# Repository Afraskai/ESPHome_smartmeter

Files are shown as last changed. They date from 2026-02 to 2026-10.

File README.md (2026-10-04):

# esphome-sml-reader

**Language:** English | [Deutsch](README.de.md)

Read your electricity meter via its infrared (IR) interface — no wiring into mains required.  
Uses an **ESP32-C3 with OLED display** (ABRobot 0.42") and a **BPW40 photodiode** to receive SML data from an ISKRA smart meter. Values are pushed to **Home Assistant** over WiFi.

> **Requirement:** Unlock the meter's IR diode first. Enter the PIN on the meter front (per your utility instructions) so the IR LED turns on and detailed SML data becomes available.

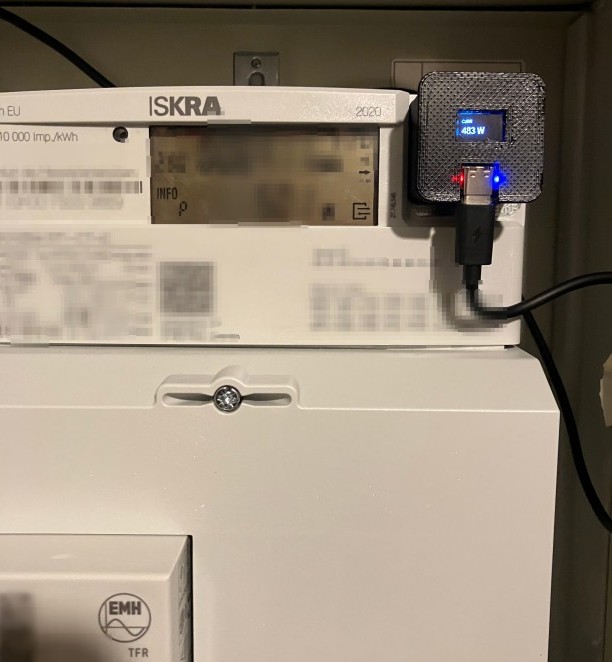
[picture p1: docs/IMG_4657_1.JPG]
Installed on meter


## Features

- **Real-time power** (W) — import and export
- **Total energy counters** (kWh) — grid import & grid export
- **Tiny OLED display** — cycles through current power, import total, export total
- **Blue LED** — blinks when data is being received
- **WiFi quality** — plain-language rating in 5 levels including dBm (e.g. `weak (-78 dBm)`)
- **Web dashboard** — built-in on port 80
- **OTA updates** — flash new firmware over WiFi

## ESPHome Web UI

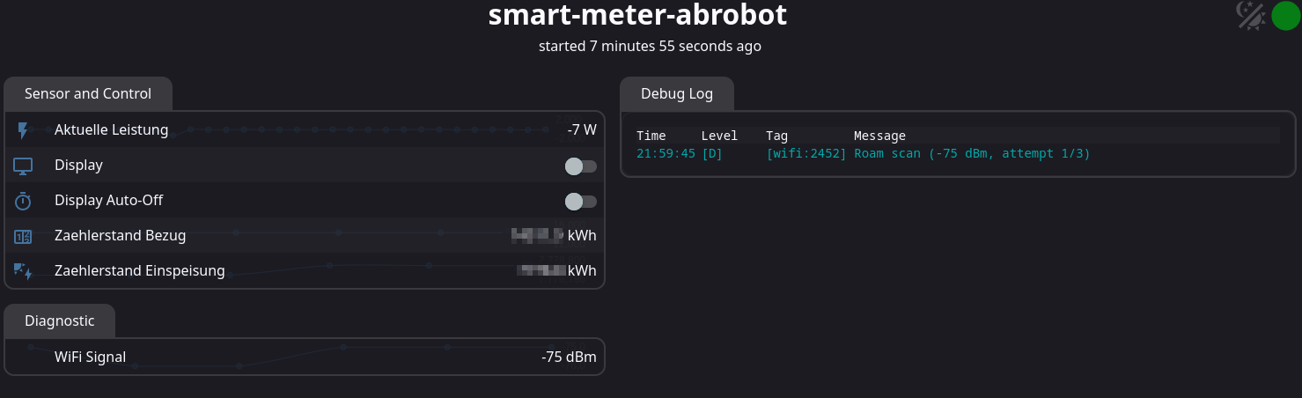
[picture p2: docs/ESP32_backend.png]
ESPHome device page


## What You Need

| Part | Notes |
|---|---|
| ESP32-C3 OLED board (ABRobot 0.42") | Has a built-in 72×40 SSD1306 display |
| BPW40 photodiode | Receives the IR signal from the meter |
| 1 kΩ resistor | Pull-down for the photodiode signal |
| 3D-printed case + magnet holder | Optional, but recommended for a clean install |
| Neodymium magnet (5 mm ⌀ × 3 mm) | Holds the case on the meter |
| USB-C cable + power supply | Powers the ESP32 inside the meter cabinet |

## Parts Overview

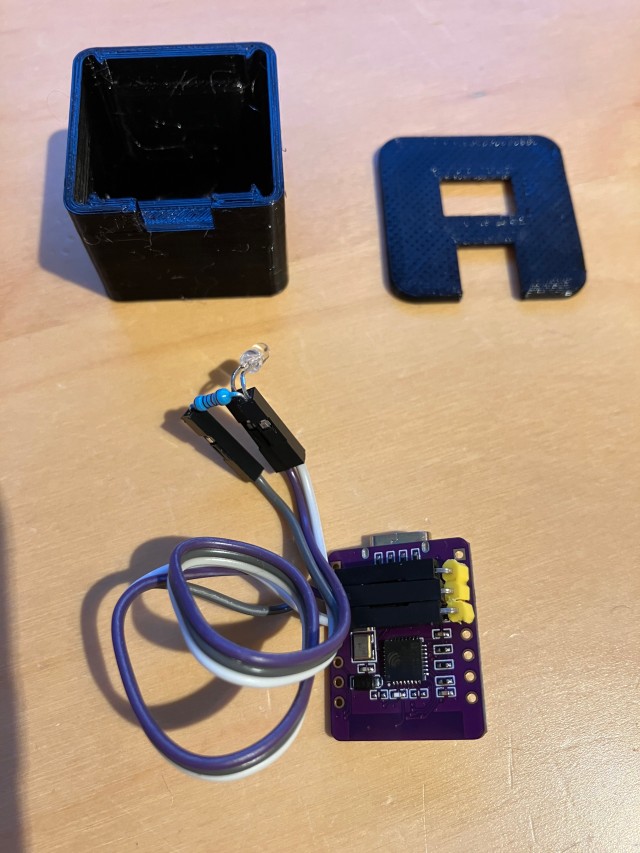
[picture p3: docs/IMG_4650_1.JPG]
Components


*Left to right: 3D-printed magnet holder, case with light-tight compartment for the photodiode, BPW40 + resistor on Dupont wires, ESP32-C3 ABRobot board.*

## Assembled Unit

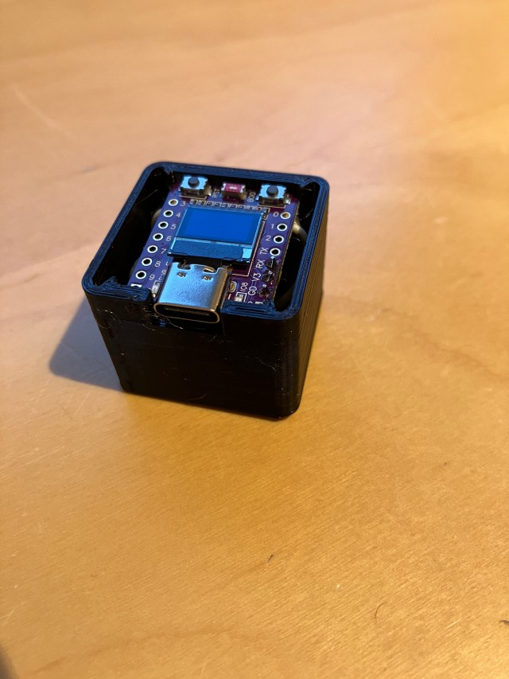
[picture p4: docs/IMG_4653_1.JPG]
ESP32 in case


*The ESP32-C3 sits in the 3D-printed case. The OLED display and USB-C port are accessible from the front.*

## Wiring Diagram

The BPW40 photodiode is connected to the ESP32-C3 with just three wires and one resistor:

```mermaid
graph LR
    subgraph "BPW40 Photodiode"
        K["Cathode (short leg)"]
        A["Anode (long leg)"]
    end

    subgraph "ESP32-C3 (ABRobot)"
        V3["3.3V"]
        RX["GPIO20 / RX"]
        GND["GND"]
    end

    R["1 kΩ Resistor"]

    K -- "purple wire" --> V3
    A -- "white wire" --> RX
    RX --> R
    R --> GND
```

> **Key point:** The photodiode is reverse-biased (cathode → 3.3V). The 1 kΩ resistor pulls GPIO20 to GND. When the meter's IR LED pulses, the photodiode conducts and the voltage on GPIO20 changes — the ESP32 UART reads this as serial SML data.

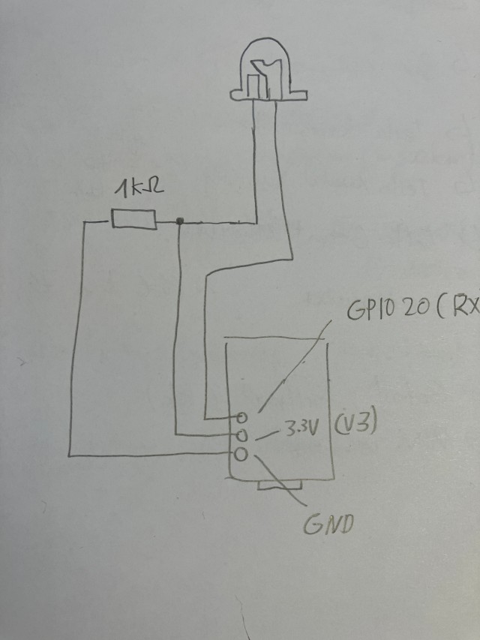
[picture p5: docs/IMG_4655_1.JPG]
Hand-drawn schematic


## Installation

1. **Flash the firmware**  
   Copy `esphome_smartmeter_en.yaml` (or `_de.yaml` for German) into your ESPHome dashboard and add your WiFi credentials to `secrets.yaml`:
   ```yaml
   wifi_ssid: "YourNetwork"
   wifi_password: "YourPassword"
   ```

   Tested with **ESPHome 2026.9.1** (dashboard or CLI).

2. **Wire the photodiode**  
   Connect the BPW40 as shown in the wiring diagram above.

3. **Prepare the 3D-printed case**  
   Depending on your printer and filament, the holes for the photodiode legs may be too tight. You might need to drill them out — a **3 mm drill bit** worked well in my case.

4. **Mount on the meter**  
   Press the neodymium magnet (5 mm ⌀ × 3 mm) into the holder. Place the photodiode directly over the meter's IR interface. It **must** be light-tight — use the 3D-printed case or black tape. The magnet snaps the unit onto the meter housing.

5. **Power up**  
   Plug in the USB-C cable. The display will show "Waiting…" until the first SML telegram arrives (usually within a few seconds).

6. **Add to Home Assistant**  
   The device will be auto-discovered via the ESPHome integration. You get three sensors:
   - **Current Power** (W)
   - **Grid Import Total** (kWh)
   - **Grid Export Total** (kWh)
   - **WiFi Quality** (text, e.g. `good (-58 dBm)`)

> **Tip:** Smart meter cabinets are often metal and shield WiFi. Make sure the ESP32 gets a reliable signal — the `WiFi Quality` sensor shows you how good it actually is.

## Installed on the Meter

Installed

*The reader sits next to the ISKRA meter in the cabinet. The OLED shows the current power draw (483 W in this photo). The blue LED confirms active data reception.*

## Display Pages

The OLED cycles automatically every 5 seconds:

| Page | Label | Value |
|---|---|---|
| 1 | `CURR` | Current power in W |
| 2 | `IMPORT` | Total grid import in kWh |
| 3 | `EXPORT` | Total grid export in kWh |

## WiFi Quality

The `WiFi Quality` text sensor rates the signal in five levels and appends the raw value in brackets — e.g. `weak (-78 dBm)`. It shows up in the web dashboard and in Home Assistant. The underlying numeric RSSI sensor is marked `internal`, so it does not appear as a separate entity.

| Signal strength | Rating |
|---|---|
| ≥ -50 dBm | excellent |
| -50 to -59 dBm | good |
| -60 to -69 dBm | fair |
| -70 to -79 dBm | weak |
| < -80 dBm | very weak |

> **Note:** Right after a restart the sensor reads `unknown` for about a minute — it polls every 60 seconds and on the first poll after boot the WiFi sensor has no value yet. The real reading follows.

## Compatibility

Tested with **ISKRA** smart meters using the **SML protocol** over IR. Should work with any SML-capable meter — you may need to adjust the OBIS codes in the YAML config for your specific meter model.

## Contributing

Contributions, issues, and feature requests are welcome! Feel free to open an issue or submit a pull request.

## License

This project is open source and available under the [MIT License](LICENSE).

## Disclaimer

This project is provided **as-is**, without any warranty of any kind, express or implied. Use it at your own risk. The author assumes **no liability** for any damage to hardware, software, or property, nor for any personal injury resulting from the use of this project. Always follow local electrical safety regulations when working near your meter cabinet.

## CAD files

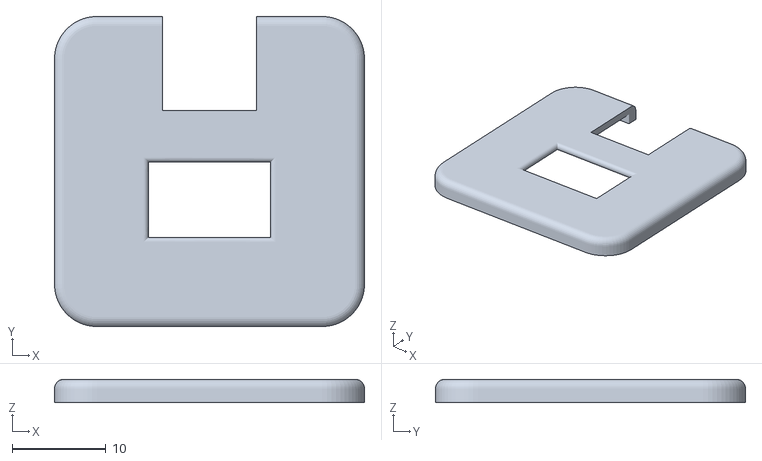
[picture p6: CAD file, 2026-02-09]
MINI_SML_lid.stl
33.0 x 33.0 x 2.50

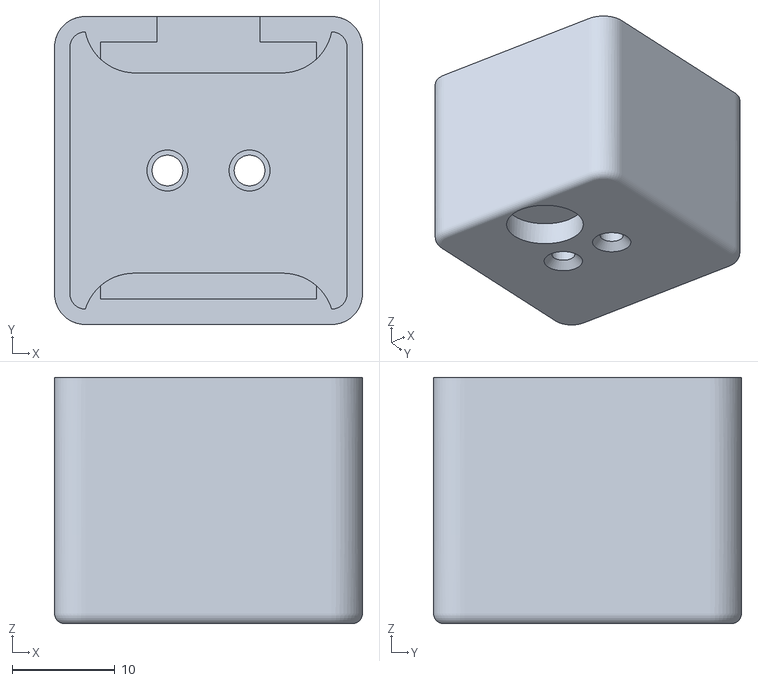
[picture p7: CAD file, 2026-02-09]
MINI_SML_case.stl
30.0 x 30.0 x 24.0

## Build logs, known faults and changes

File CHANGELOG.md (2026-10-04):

# Changelog

## [1.1.1] - 2026-10-04

### Changed
- The raw RSSI sensor is now marked `internal`. It only feeds the `WiFi Qualitaet`
  text sensor and no longer shows up as an entity of its own in the web UI or in
  Home Assistant. The dBm value is still part of the text sensor's output.

## [1.1.0] - 2026-10-04

Verified against **ESPHome 2026.9.1**: the previous configuration built unchanged
and was flashed and tested on the device (SML reception, OLED pages, web UI, OTA).
Both language variants of this release compile cleanly (ESP-IDF toolchain,
RAM 32.9 %, flash 52.4 %).

### Added
- `WiFi Qualitaet` text sensor: plain-language WiFi rating in 5 levels with the
  raw dBm value in brackets (e.g. `schwach (-78 dBm)`). Shows up in the ESPHome
  web UI and in Home Assistant next to the numeric `WiFi Signal` sensor.

### Notes
- Since ESPHome 2026.7.0, ESP32 builds default to the native `esp-idf` toolchain.
  `framework: type: arduino` keeps working, but the `platformio` toolchain is
  deprecated and will be removed in 2027.2.0.

## [1.0.0] - 2026-06-20

ESPHome 2026.3.0+ changed the web_server default from v1 (embedded UI) to v2/v3
(CDN-based JS architecture). The previous config without an explicit `version:`
silently inherited the new architecture, but the CDN-loaded frontend JS did not
render sensor values correctly on this device.

### Fixed
- Web UI blank after ESPHome upgrade (v2/v3 require `version:` to be set
  explicitly, or `local: true` for embedded assets) → added `version: 3`

## [0.1.0] - 2026-XX-XX
### Added
- Initial release: ISKRA SML reader with ESP32-C3 OLED + BPW40 photodiode
- SML sensors (power, grid import total, grid export total)
- OLED display with page rotation (CURR / IMPORT / EXPORT)
- Blue LED blink on data reception
- Display auto-off after 5 minutes
- WiFi, OTA, API, web_server support
- 3D-printable case (STL files)
- English & German READMEs

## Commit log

2026-02-09 new: init version
    [MINI_SML_case.stl, MINI_SML_lid.stl]
2026-10-04 feat: add WiFi quality text sensor with 5-level rating
    Adds a template text sensor that turns the raw RSSI into plain language
    (sehr gut / gut / mittel / schwach / sehr schwach) and appends the dBm
    value in brackets, e.g. "schwach (-78 dBm)". Visible in the ESPHome web
    UI and Home Assistant next to the numeric WiFi Signal sensor.
    The wifi_signal sensor needed an id to be referenced from the lambda;
    it is named wifi_rssi because "wifi_signal" collides with the
    integration name. The rating is formatted with snprintf since the
    printf-style braced init no longer converts to std::optional<std::string>.
    Verified with esphome 2026.9.1: config validates and compiles for both
    language variants (RAM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
2026-10-04 docs: document ESPHome 2026.9.1 verification and WiFi quality sensor
    Adds the 1.1.0 changelog entry (previous config built and ran unchanged
    on ESPHome 2026.9.1, tested on the device) and documents the new WiFi
    quality text sensor plus its level thresholds in both READMEs. Also
    notes that ESP32 builds default to the esp-idf toolchain since
    ESPHome 2026.7.0.
2026-10-04 fix: hide the raw RSSI sensor behind the WiFi quality text sensor
    The numeric WiFi Signal sensor was only there to feed the lambda of the
    new text sensor, so it is now marked internal. It keeps polling locally
    but is no longer listed in the web UI or sent to Home Assistant
    (web_server.cpp and api_server.cpp both skip internal entities).
    language variants.
    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
2026-10-04 docs: add 1.1.1 changelog entry and startup note for WiFi quality
    Documents the internal RSSI sensor as a 1.1.1 entry instead of
    rewriting the already published 1.1.0 notes, and explains in both READMEs
    why the text sensor reads "unbekannt"/"unknown" for the first minute
    after a restart.
